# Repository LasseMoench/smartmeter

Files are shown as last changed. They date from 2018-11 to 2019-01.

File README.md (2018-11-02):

# ESP8266 Smart Energy Meter

This project aims to build a smart energy meter, getting readings from our ferraris energy meter (which we are not allowed to modify) by detecting a red stripe on a spinning wheel using an IR-diode and an IR-receiver.

## Setting up the API
On the machine that shall run the API, clone the repository and install the requirements listed in requirements.txt (maybe you will want to use a virtualenv or something like this). You are now ready to run the API using
```
python3 api.py
```
You can test if it works correctly using curl:
```
curl localhost:8080/tick
```
You can use the provided systemd service file as an example to run the API as a systemd service.

## Setting up the ESP

Upload the sketch to the ESP, connect the IR-LED, the IR-receiver and the resistor like shown in the wiring diagram. Attach the ESP to your computer and hold it to the Ferraris counter. Find a position that works best (where you have a clear change in the readings when the red stripe passes). Fix it. Set the correct IP, WiFi-password and name in the ESP as well as a threshold level that works for you. For me, the reading would drop from 200 to 100 while the red stripe was on, so I chose 150 as a threshold.

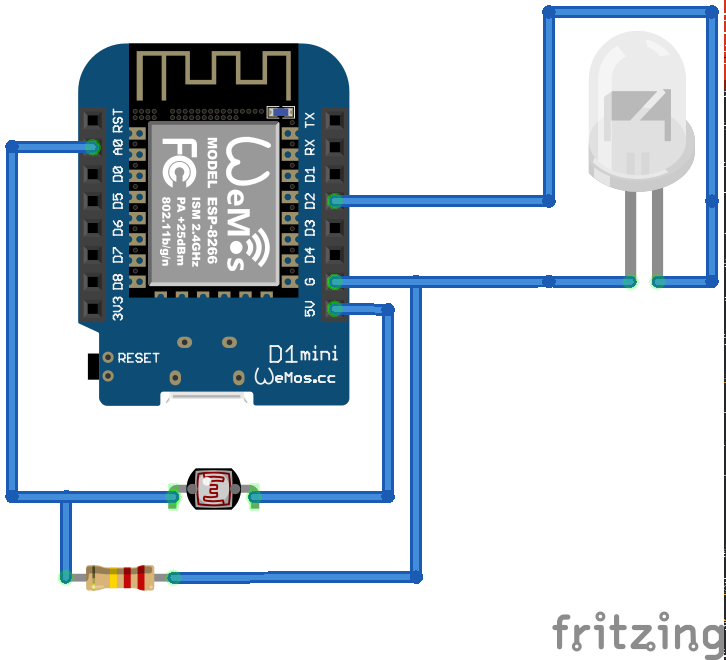
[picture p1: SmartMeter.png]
Wiring Breadboard View Smart Meter

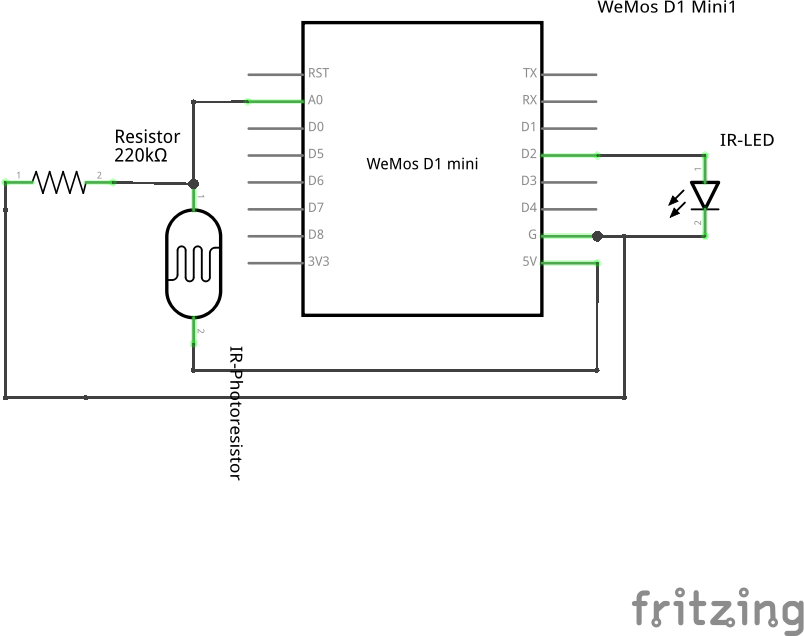
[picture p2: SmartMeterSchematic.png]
Wiring Schematic View Smart Meter Schematic


## Acknowledgments

Thanks to [Martin Kompf](https://www.kompf.de/tech/emeir.html) for inspiring me to do this project as well as useful info on the IR-led and receiver.

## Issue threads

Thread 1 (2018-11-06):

Multiple ticks on the same stripe

LasseMoench, 2018-11-06:
Sometimes, the ESP will call the api multiple times on the same stripe. This results in unrealistically high calculations for current energy usage (above 200kW), as well as wrong historical data. We need to prevent this (e.g. do a reality check, would the resulting energy consumption be above 50kW?).

LasseMoench, 2018-11-09:
Fixed and cleaned historical data

Closed 2018-11-09.

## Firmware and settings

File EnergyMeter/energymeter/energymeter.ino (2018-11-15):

#include <ESP8266WiFi.h>

#define IRLED 4

int withLed = 0;
int withoutLed = 0;
int stripeCount = 0;
int diff = 0;
bool disconn = false;
unsigned long disconnTime = 0;
unsigned long duration = 0;
unsigned long lastTick = 0;
int ticksMissed = 0;
WiFiClient client;

const int threshold = 150;

// Wi-Fi Settings
const char* ssid = "Bergernetz"; // your wireless network name (SSID)
const char* password = "GrummelKeks1"; // your Wi-Fi network password
const char* apiIP = "192.168.0.38";

void setup() {
  Serial.begin(115200);
  WiFi.begin(ssid, password);
  WiFi.mode(WIFI_STA);
  Serial.print("Connecting to WiFi");
  pinMode(IRLED, OUTPUT);

  while (WiFi.status() != WL_CONNECTED) {
    delay(500);
    Serial.print(".");
  }
  Serial.println("Connected to WiFi!");
}

void loop() {

  if (WiFi.status() != WL_CONNECTED && !disconn) {
      disconn = true;
      disconnTime = millis();
      Serial.println("Lost WiFi connection!");
    };

  if (WiFi.status() == WL_CONNECTED && disconn) {
      disconn = false;
      duration = millis() - disconnTime;
  
      //Report the disconnect to the API
      if (client.connect(apiIP, 80)){
        // we are connected to the host!
        client.print(String("GET /connloss/")+ disconnTime + "/" + ticksMissed + " HTTP/1.1\r\n" +
             "Host: " + apiIP + "\r\n" +
             "Connection: close\r\n" +
             "\r\n"
            );
        Serial.println("Reporting disconnect!");
        while (client.connected()){
          if (client.available()){
            String line = client.readStringUntil('\n');
            Serial.println(line);
          }
        }
        client.stop();
        Serial.println("\n[Disconnected]");
        ticksMissed = 0;
      }else{
        // connection failure
        Serial.println("Connection to API failed!");        
      }
      
    }

  //Read without LED first, then switch the LED on and read again. This will filter out IR light that is not generated by the LED.
  withoutLed = analogRead(A0);
  
  digitalWrite(IRLED, LOW);

  delay(10);

  withLed = analogRead(A0);

  digitalWrite(IRLED, HIGH);

  diff = withoutLed - withLed;

//    Serial.print("Without LED: ");
//    Serial.println(withoutLed);

//    Serial.print("With LED: ");
//    Serial.println(withLed);

//    Serial.print("Difference is: ");
//    Serial.println(diff);

  //We are detecting a stripe! (Reality check: last tick was at least 1 sec ago -> less than 50kW usage)
  if(diff < threshold && millis() - lastTick > 1000){
    stripeCount++;
  }

  //We were detecting a stripe and it has just ended!
  if(diff > threshold && stripeCount > 0){
    stripeCount = 0;

    //Report the stripe to the API
    if (client.connect(apiIP, 80)){
      // we are connected to the host!
      client.print(String("GET /tick") + " HTTP/1.1\r\n" +
           "Host: " + apiIP + "\r\n" +
           "Connection: close\r\n" +
           "\r\n"
          );
      Serial.println("Reporting tick!");
      while (client.connected()){
        if (client.available()){
          String line = client.readStringUntil('\n');
          Serial.println(line);
        }
      }
      client.stop();
      Serial.println("\n[Disconnected]");
      lastTick = millis();
    }else{
      // connection failure
      Serial.println("Connection to tick-API failed!");    
      ticksMissed++;    
    }
  }

  //The led probably needs some time to switch on and off
  delay(20);
}

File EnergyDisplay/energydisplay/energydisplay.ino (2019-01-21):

#include <ArduinoJson.h>

#include <Wire.h>  // Only needed for Arduino 1.6.5 and earlier
#include "SSD1306Wire.h" // legacy include: `#include "SSD1306.h"`

#include <ESP8266WiFi.h>
#include <ESP8266HTTPClient.h>

// Initialize the OLED display using Wire library
SSD1306Wire  display(0x3c, D2, D1);
// SH1106 display(0x3c, D3, D5);

const char* ssid = "Bergernetz"; // your wireless network name (SSID)
const char* password = "GrummelKeks1"; // your Wi-Fi network password
const char host[] = "http://192.168.0.38/lcdinfo";
String result;
WiFiClient client;

void setup() {
  Serial.begin(115200);
  
  // Initialising the UI will init the display too.
  display.init();

  display.flipScreenVertically();
  display.setFont(ArialMT_Plain_10);

  display.clear();
  
  display.setTextAlignment(TEXT_ALIGN_CENTER);
  display.setFont(ArialMT_Plain_16);
  display.drawString(64, 24, "Connecting...");
  display.display();

  WiFi.begin(ssid, password);
  Serial.print("Connecting to WiFi");

  while (WiFi.status() != WL_CONNECTED) {
    delay(500);
    Serial.print(".");
  }
  Serial.println("Connected to WiFi!");
  display.clear();
}

void loop() {

  HTTPClient http;
  http.begin(host);
  int statusCode = http.GET();
  result = http.getString();
  Serial.println(result);
  Serial.println(statusCode);
  Serial.println(http.errorToString(statusCode).c_str());
  http.end();

  
  StaticJsonBuffer<200> jsonBuffer;
  JsonObject& root = jsonBuffer.parseObject(result);

  String wh = root["daily_power"];
  String current = root["current_power"];

  if(!root.success()) {
    Serial.println("parseObject() failed");
  }
  
  display.clear();
  display.setFont(ArialMT_Plain_10);
  display.setTextAlignment(TEXT_ALIGN_LEFT);
  display.drawString(0, 0, "Now:");
  display.setTextAlignment(TEXT_ALIGN_RIGHT);
  display.drawString(128, 0, current + "W");
  display.setTextAlignment(TEXT_ALIGN_LEFT);
  display.drawString(0, 16, "Today:");
  display.setTextAlignment(TEXT_ALIGN_RIGHT);
  display.drawString(128, 16, wh + "Wh");
  float daily = root["daily_power"];
  float cost = 0.0002775 * daily;
  String coststr = String(cost);
  display.setTextAlignment(TEXT_ALIGN_LEFT);
  display.drawString(0, 32, "Cost:");
  display.setTextAlignment(TEXT_ALIGN_RIGHT);
  display.drawString(128, 32, coststr + "EUR");
  display.display();
  client.stop();

  delay(30000);
}

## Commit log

2018-11-02 Add wiring diagrams
    [SmartMeter.fzz]
2018-11-05 First working html frontend prototype
2018-11-05 Switch to using jinja templates
2018-11-05 Update socket name
2018-11-08 Improve graph, fix double tick on single stripe
    [energymeter.ino]
2018-11-08 Add scripts to detect and correct doubleticks in history
    [energymeter.ino]
2018-11-15 Switch to OLED display
